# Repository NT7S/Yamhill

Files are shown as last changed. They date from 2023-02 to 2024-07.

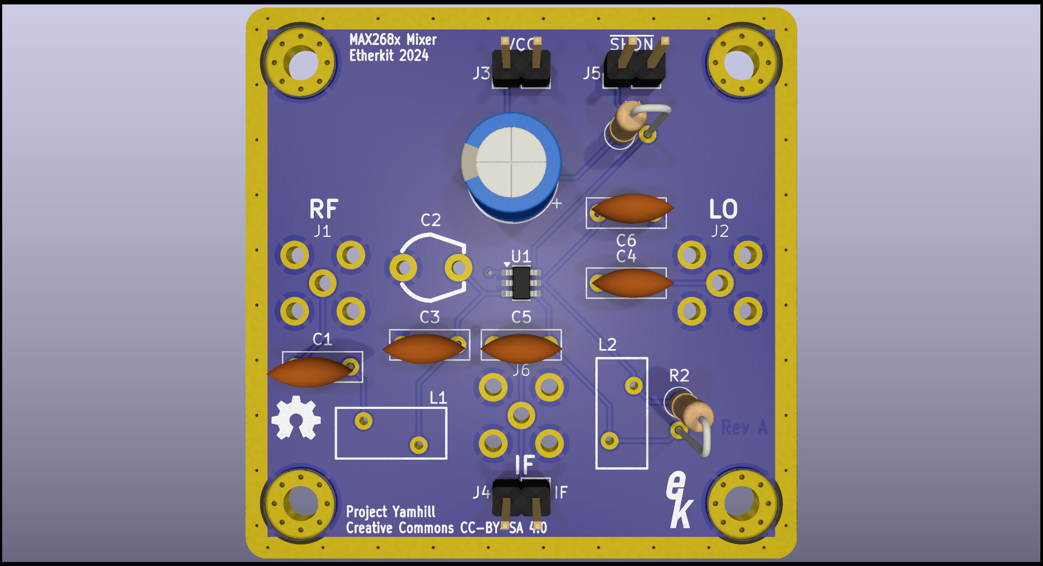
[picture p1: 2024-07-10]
PCB/YamhillMAX2680Mixer/YamhillMAX2680Mixer.png

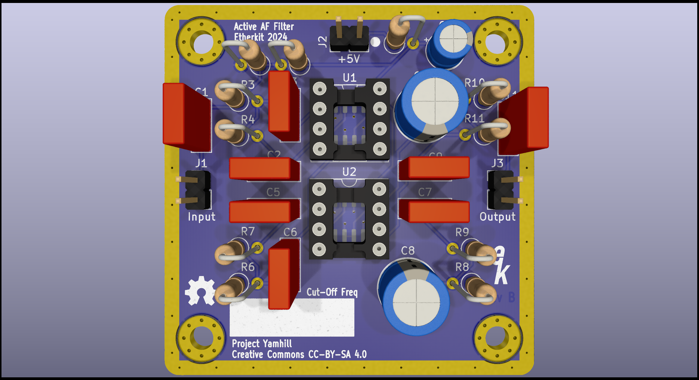
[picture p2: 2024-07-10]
PCB/YamhillActiveAFFilter/YamhillActiveAFFilter.png

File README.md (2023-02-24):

# Project Yahmill
Jason Milldrum, NT7S<br/>
Etherkit LLC<br/>

Project Yamhill is the successor to the Willamette Transceiver, also known as the qrp-l Group Project. The purpose of this endeavor is to provide a platform to learn about radio electronics at a system level. Modules that correspond to the blocks of a block diagram will be the basis upon which different types of radio designs will be created. A modular 3D printed backplane will be the chassis, user interface, and power supply for the radio experiments. The desired goal is to have a high-performance CW QRP transceiver at the end of the main project run, however there would be the capacity to build many other types of radios from the blocks as desired, such as a SSB transceiver, run more transmit power with a linear amplifier that can provide 20 watts or more, data radio, simple receiver, different architectures such as a phasing receiver, etc.

All designs and code will be permissively open sourced so that an end user is able to build one by himself if desired. All radio design specifications will be published, along with detailed information about how the user can make his own measurements with affordable test equipment to ensure that his radio is performing as expected. Basic build information will be freely available, however for detailed instructions, please subscribe to my Substack, details below.

## Substack Community
Detailed build, test, and alignment instructions will be posted on my Substack, [Applied Etherics](https://nt7s.substack.com/). You'll also find support and the build community there.

## Architecture
The system architecture white paper can be found [here](YamhillArchitecture.md).

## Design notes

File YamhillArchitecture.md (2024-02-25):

# Project Yamhill Architecture

Jason Milldrum, NT7S<br/>
Etherkit LLC<br/>
Revision: 25 February 2024

## Overview

Project Yamhill is the successor to the Willamette Transceiver, also known as the qrp-l Group Project. The purpose of this endeavor is to provide a platform to learn about radio electronics at a system level. Modules that correspond to the blocks of a block diagram will be the basis upon which different types of radio designs will be created. A modular 3D printed backplane will be the chassis, user interface, and power supply for the radio experiments. The desired goal is to have a high-performance CW QRP transceiver at the end of the main project run, however there would be the capacity to build many other types of radios from the blocks as desired, such as a SSB transceiver, run more transmit power with a linear amplifier that can provide 20 watts or more, data radio, simple receiver, different architectures such as a phasing receiver, etc.

All designs and code will be permissively open sourced so that an end user is able to build one by himself if desired. All radio design specifications will be published, along with detailed information about how the user can make his own measurements with affordable test equipment to ensure that his radio is performing as expected.

## Backplane

The Yamhill backplane will be the foundation of every radio experiment in this project. Designed to be printed on a consumer-grade FDM 3D printer, it will hold all of the necessary block modules open-air in a reconfigurable grid, have an integrated power supply and power distribution system, have rear connectors needed for a complete transceiver, and house the front panel with the user interface, including microcontroller, LCD display, buttons, encoder tuning knob, etc.

Possibly two sizes, but we're going to start with the largest and see if there is demand for a more compact version.

### Block Module Grid

A grid of mounting holes for M3(?) screws to secure block module PCBs to the backplane will be spaced at 4 cm in each axis, with allowance for 5 mm of margin from the outside board edge at each mounting hole, with a 1 cm x 1 cm x 1 cm cable management channel being provided between each row and column of mounting holes.

Therefore, allowable PCB sizes will be 5 cm x 5 cm, 5 cm x 11 cm, 11 cm x 11 cm, 11 cm x 17 cm, etc.

### Signal Routing

DC power is to be provided by and distributed through a PCB that integrates with the backplane. Channels to be provided in the backplane (1 cm width?) for easy and neat distribution of other signals.

### On-board Rear Panel Connectors

- BNC (x2)
- SMA (x2)
- DC barrel (5.5 x 2.1 mm)
- 3.5 mm TRS (x2)
- USB-C (for UART)

### Front Panel

A front panel PCB will hold most of the user interface and brains of Project Yamhill. This PCB will be populated with:
- Raspberry Pi Pico microcontroller
- Color LCD display module with touchscreen
- Large tuning encoder
- Smaller encoders (for multifunction usage)
- AF gain pot if not encoder controlled
- A plethora of microswitch pushbuttons
- A handful of status LEDs
- ADC channels for measuring things like PSU voltage, SWR, etc.
- Two 3.5 mm TRS jacks (Morse paddle and headphones)
- Microphone jack (RJ-45?)
- AF Power Amplifier
- Microphone Amplifier
- Speaker (not sure if front-firing or chassis-mounted)
- Transmit, mute, and extra GPIO pins available on pin headers for project use
- Audio and microphone signals routed to Pico ADC pins for future DSP usage
- Pico DAC pin routed to AF power amp for sidetone use and future DSP usage

The front panel PCB will have a USB connection for programming the microcontroller, as well as at least one UART available for rig control, debugging purposes, etc.

## Block Modules

Block modules are self-contained PCBs that will perform the functions of a block on the block diagram of a radio. Most components on front panel PCB will be SMT, and those boards sold by Etherkit will have the SMT components installed by the manufacturer. Most individual modules will be through-hole, unless there are no non-SMT options for a component.

### List

- PSU/Power Distribution (special case, backplane integration)
    - 12 V rail, derived from exterior PSU, minimum 1 A
    - 5 V rail, minimum 500 mA(?)
    - 3.3 V rail, minimum 100 mA
    - LED indicators
    - Reverse polarity and overcurrent protection
    - Inputs: 12 VDC, 2 A
    - Outputs: 12 VDC, 5 VDC regulated, 3.3 VDC regulated
- AF Power Amplifier (included in front panel PCB)
    - 60 dB AF gain
    - Able to drive a 1 W speaker or phones
    - AF gain control
    - Sidetone injection
    - Transceive muting
- AF Preamplifier For DC receiver
    - Based on W7ZOI AF Feedback Amplifier
    - ~40 dB AF gain for use in a DC receiver
    - Diplexer on input for good termination of mixer
- Grounded Gate JFET RF Preamp
    - Mainly for direct conversion receiver front end
- Microphone Amplifier (include in front panel PCB)
- Audio Filter
    - DSP CODEC?
- Double-balanced Diode Ring Mixer/Modulator
    - Option for higher than level 7?
- KISS Mixer
- Tayloe Detector
- Crystal Ladder IF Filter
    - Various bandwidths available for SSB, CW, roofing
- IF Amplifier with AGC
- Receive Bandpass Filter
- Receive Bandpass Filter MUX
- Transmit Low-pass Filter
- Transmit Low-pass Filter MUX
- Transmit/Receive Switch
- Wideband Oscillator
    - Most likely Si5351C, but open to options
- Transmit Preamplifier
- QRP Transmit Linear Amplifier
    - Maximum power output 5 W
- Higher Power Transmit Linear Amplifier
    - Maximum power output 20 W
- GPS Receiver
    - 10 MHz ref out
    - 1 PPS out
- SWR Bridge
- S-meter Detector
- Signal Distribution(?)
- Experimenter Board (grid of Manhattan pads, connectors pads available on edge, few different sizes)

### Inter-module RF Signal Interconnects

SMA PCB mount jacks and RG-316 coax with SMA connectors

### Inter-module DC/AF Signal Interconnects

0.1 inch pin headers and Dupont wiring harnesses

## Proposed Learning Units

- Direct Conversion Receiver
- QRP CW Transmitter
- DSB Transmitter/Transceiver
- Superheterodyne CW QRP Transceiver
- WSPR Transmitter
- Superheterodyne SSB/CW QRP Transceiver

## QRP CW Transceiver Target Specifications

TBD

## Expected Required Test Equipment

- DVM
- Oscilloscope
- Spectrum analyzer such as tinySA
- VNA such as nanoVNA

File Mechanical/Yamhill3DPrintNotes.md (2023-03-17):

# Project Yamhill 3D Print Notes

The Project Yamhill backplane was designed so that it could printed on a consumer-grade FDM 3D printer. Since the total size of the backplane is 350 mm x 360 mm, the backplane is composed of four modular sections that are connected together with support brackets and M3x5 screws. Two right side and two left side modules comprise the entire base of the backplane. The front panel is secured to the front of the backplane using pairs of support brackets connected to screw holes on the vertical side of the backplane blocks.

## Material
This backplane is designed to be printed in PETG filament, although other materials such as ABS may work as well. PLA is not recommened due to its unsuitable properties for affixing screws directly to it. PLA may be usable if you modify the screw holes to accept brass heat-set inserts.

## Suggest Slicer Settings
- Infill: 20%
- Wall Line Count: 3
- Top/Bottom Layer Count: 4
- Generate Support: On (for the cable channels)

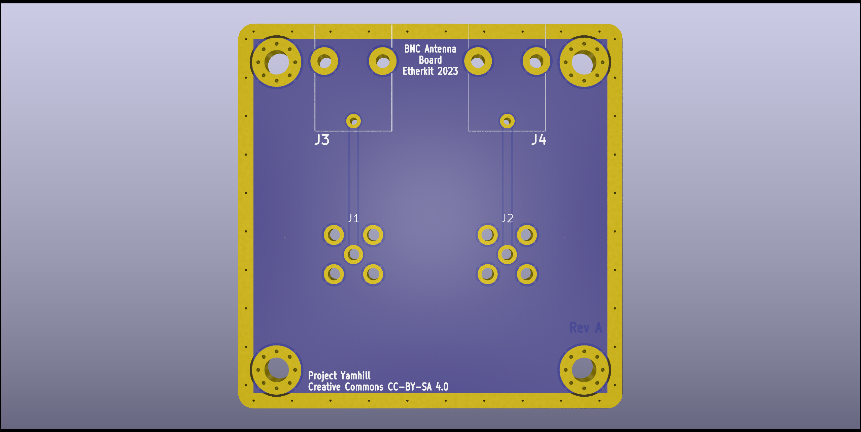
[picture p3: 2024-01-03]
PCB/YamhillBNCAntennaBoard/YamhillBNCAntennaBoard.png

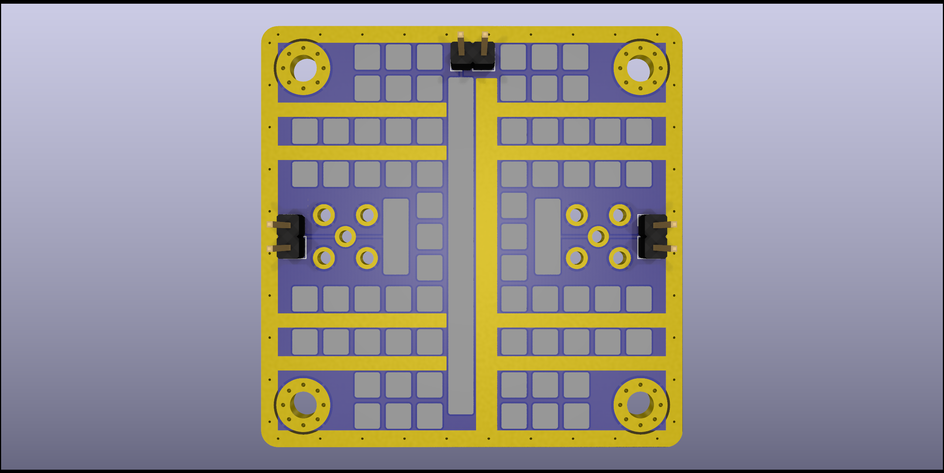
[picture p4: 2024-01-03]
PCB/YamhillProtoBoard1x1/YamhillProtoBoard1x1.png

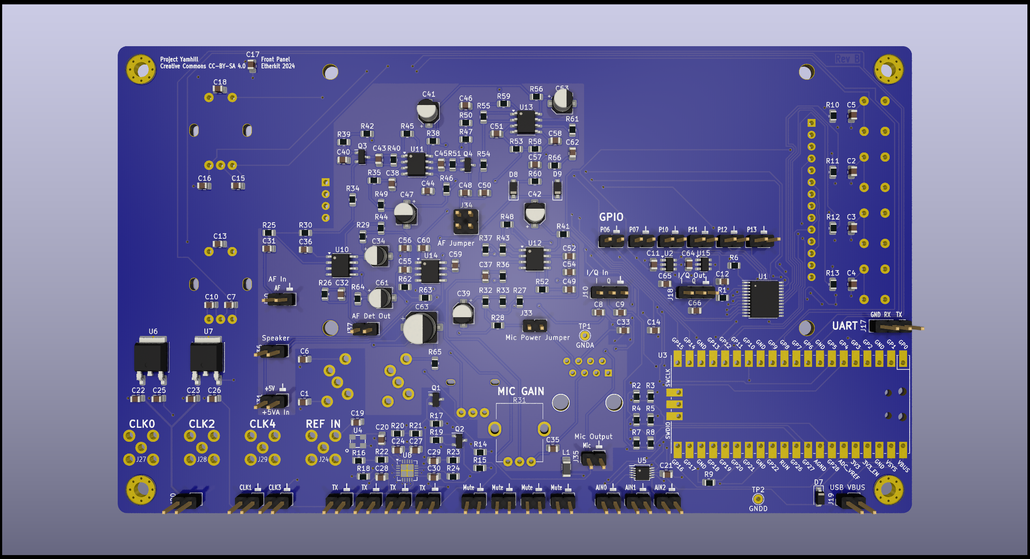
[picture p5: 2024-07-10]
PCB/YamhillFrontPanel/YamhillFrontPanelBack.png

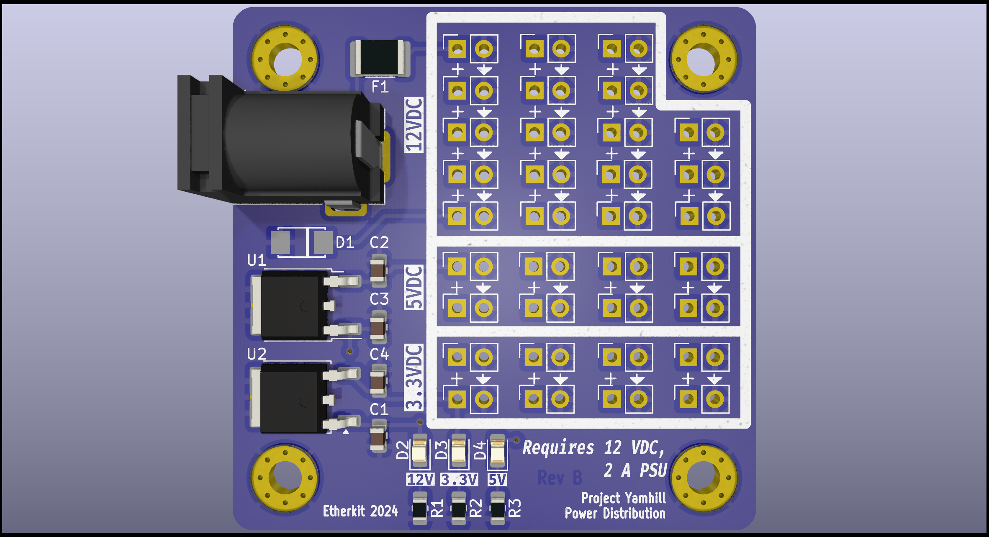
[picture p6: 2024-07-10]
PCB/YamhillPowerDistribution/YamhillPowerDistribution.png

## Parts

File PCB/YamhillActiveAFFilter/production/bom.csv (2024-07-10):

Designator | Footprint | Quantity | Value | LCSC Part #
C1, C11 | C_Rect_L7.0mm_W2.5mm_P5.00mm | 2 | 1u
C10, C8 | CP_Radial_D8.0mm_P3.50mm | 2 | C_Small
C2, C3, C5, C6, C7, C9 | C_Rect_L7.0mm_W2.5mm_P5.00mm | 6 | C_Small
C4 | CP_Radial_D5.0mm_P2.50mm | 1 | 10u
H1, H2, H3, H4 | MountingHole_3.2mm_M3_Pad_Via | 4 | MountingHole_Pad
J1 | PinHeader_1x02_P2.54mm_Vertical | 1 | Input
J2 | PinHeader_1x02_P2.54mm_Vertical | 1 | +5V
J3 | PinHeader_1x02_P2.54mm_Vertical | 1 | Output
R1, R2 | R_Axial_DIN0207_L6.3mm_D2.5mm_P2.54mm_Vertical | 2 | 10k
R10, R11, R3, R4, R6, R7, R8, R9 | R_Axial_DIN0207_L6.3mm_D2.5mm_P2.54mm_Vertical | 8 | R_US
R5 | R_Axial_DIN0207_L6.3mm_D2.5mm_P2.54mm_Vertical | 1 | 47
U1, U2 | DIP-8_SOIC-8_Combo | 2 | TLV9362

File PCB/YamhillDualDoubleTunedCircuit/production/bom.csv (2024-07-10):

Designator | Footprint | Quantity | Value | LCSC Part #
C1, C10, C12, C13, C2, C3, C5, C6, C8, C9 | C_Rect_L7.0mm_W2.5mm_P5.00mm | 10 | C
C11, C14, C4, C7 | TRIMCAP-MURATA | 4 | C_Trim
H1, H2, H3, H4 | MountingHole_3.2mm_M3_Pad_Via | 4 | MountingHole_Pad
J1, J4 | SMA_Jack_Vertical | 2 | SMA
J2, J3 | PinHeader_1x03_P2.54mm_Vertical | 2 | Filter Sel
L1, L2, L3, L4 | T37-V | 4 | L_Iron

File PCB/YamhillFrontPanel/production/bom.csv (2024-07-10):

Designator | Footprint | Quantity | Value | LCSC Part #
C1, C10, C11, C12, C13, C14, C15, C16, C17, C18, C19, C2, C21, C24, C25, C26, C27, C28, C29, C3, C30, C33, C4, C5, C55, C56, C6, C64, C65, C66, C7, C8, C9 | 0805 | 33 | 100n
C20, C52 | 0805 | 2 | 10n
C22, C23, C31, C32, C35, C37, C38, C40, C44, C46, C48, C50, C51, C54, C57, C58, C59, C60, C62 | 0805 | 19 | 1u
C34, C39, C41, C42, C47, C53, C61 | CP_Elec_4x4.5 | 7 | 10u
C36, C43, C45 | 0805 | 3 | 1n
C49 | 0805 | 1 | 2.7n
C63 | CP_Elec_6.3x5.9 | 1 | 100u
D1, D3, D4, D6 | 0805 | 4 | LED
D2, D5 | LED_WS2812B_PLCC4_5.0x5.0mm_P3.2mm | 2 | WS2812B
D7, D8, D9 | D_SOD-123 | 3 | MBRX120LF-TP
H1, H2, H3, H4 | MountingHole_3.2mm_M3_Pad_Via | 4 | MountingHole_Pad
J1, J2, J3, J4 | PinHeader_1x02_P2.54mm_Vertical | 4 | TX
J10 | PinHeader_1x03_P2.54mm_Vertical | 1 | I/Q In
J11 | PinHeader_1x02_P2.54mm_Vertical | 1 | P06
J12 | PinHeader_1x02_P2.54mm_Vertical | 1 | P07
J13 | PinHeader_1x02_P2.54mm_Vertical | 1 | P10
J14 | PinHeader_1x02_P2.54mm_Vertical | 1 | P11
J15 | PinHeader_1x02_P2.54mm_Vertical | 1 | P12
J16 | PinHeader_1x02_P2.54mm_Vertical | 1 | P13
J17 | PinHeader_1x03_P2.54mm_Vertical | 1 | UART
J18 | PinHeader_1x03_P2.54mm_Vertical | 1 | I/Q Out
J19 | PinHeader_1x02_P2.54mm_Vertical | 1 | USB VBUS
J20 | PinHeader_1x02_P2.54mm_Vertical | 1 | +12V IN
J21 | PinHeader_1x02_P2.54mm_Vertical | 1 | AIN0
J22 | PinHeader_1x02_P2.54mm_Vertical | 1 | AIN1
J23 | PinHeader_1x02_P2.54mm_Vertical | 1 | AIN2
J24 | SMA_Jack_Vertical | 1 | REF_IN
J25 | PinHeader_1x02_P2.54mm_Vertical | 1 | CLK1
J26 | PinHeader_1x02_P2.54mm_Vertical | 1 | CLK3
J27 | SMA_Jack_Vertical | 1 | CLK0
J28 | SMA_Jack_Vertical | 1 | CLK2
J29 | SMA_Jack_Vertical | 1 | CLK4
J30 | PinHeader_1x02_P2.54mm_Vertical | 1 | AF In
J31 | PinHeader_1x02_P2.54mm_Vertical | 1 | +5VA In
J32 | RJ45_OST_PJ012-8P8CX_Vertical | 1 | Microphone
J33 | PinHeader_1x02_P2.54mm_Vertical | 1 | Mic Power Jumper
J34 | PinHeader_2x02_P2.54mm_Vertical | 1 | AF Jumper
J35 | PinHeader_1x02_P2.54mm_Vertical | 1 | Mic Output
J36 | PinHeader_1x02_P2.54mm_Vertical | 1 | Speaker
J37 | PinHeader_1x02_P2.54mm_Vertical | 1 | AF Det Out
J38 | Kycon_STX-3680-5NB | 1 | Headphones
J5, J6, J7, J8 | PinHeader_1x02_P2.54mm_Vertical | 4 | MUTE
J9 | Kycon_STX-3680-5NB | 1 | Paddles
L1 | 1206 | 1 | Fair-Rite 2512066017Y1
Q1, Q2, Q3, Q4 | SOT-23 | 4 | 2N7002
R1, R18, R32, R33, R40, R44, R48, R49, R51, R52, R59, R6, R61 | 0805 | 13 | 10k
R10, R11, R12, R13 | 0805 | 4 | 330
R14, R15, R17, R19, R54 | 0805 | 5 | 4.7k
R16, R20, R21, R22, R23, R24, R29, R38, R41, R56 | 0805 | 10 | 47
R2, R3, R4, R5, R7, R8 | 0805 | 6 | 47k
R25 | 0805 | 1 | 100
R26, R35, R36, R39, R46, R50, R53, R55, R58, R62, R63, R64 | 0805 | 12 | 100k
R27, R37, R42, R9 | 0805 | 4 | 470
R28 | 0805 | 1 | 7.5k
R30, R34, R45, R47, R60, R66 | 0805 | 6 | 1k
R31 | Bournes_PTV09A-4 | 1 | 5k trim
R43 | 0805 | 1 | 270k
R57 | Alps_RK09L1140 | 1 | 10k
R65 | 0805 | 1 | 150
S1, S2, S3, S4 | E-Switch_TL1105 | 4 | PUSHBUTTON_TACTILE
SW1 | Bournes_PEC11R-4xxxF-Sxxxx | 1 | Tune
SW2 | Bournes_PEC11R-4xxxF-Sxxxx | 1 | Multifunction
TP1 | TestPoint_THTPad_D2.0mm_Drill1.0mm | 1 | GNDA
TP2 | TestPoint_THTPad_D2.0mm_Drill1.0mm | 1 | GNDD
U1 | TSSOP-24_6.1x7.8mm_P0.65mm | 1 | TCAL6416PWR
U10, U11, U12, U13 | SOIC-8_3.9x4.9mm_P1.27mm | 4 | TLV9362
U14 | SOIC-8_3.9x4.9mm_P1.27mm | 1 | LM4875
U15, U2 | SOT-23-6 | 2 | MCP4725A1T-E/CH
U3 | RPi_Pico_SMD_TH | 1 | Pico
U4 | ASTX-H11-25.000MHZ-T | 1 | ATX-H11-F-25.000MHZ-F25-T
U5 | TSSOP-10_3x3mm_P0.5mm | 1 | ADS1115IDGS
U6 | TO-252-2 | 1 | UA78M33CKVURG3
U7 | TO-252-2 | 1 | UA78M05IKVURG3
U8 | QFN-20-1EP_4x4mm_P0.5mm_EP2.7x2.7mm_ThermalVias | 1 | Si5351C
U9 | ST7796_4.0in | 1 | 4" TFT LCD ST7796S

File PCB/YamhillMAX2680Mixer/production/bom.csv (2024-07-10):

Designator | Footprint | Quantity | Value | LCSC Part #
C1, C4, C6 | C_Disc_D7.0mm_W2.5mm_P5.00mm | 3 | 100n
C2 | TRIMCAP-MURATA | 1 | ~
C3 | C_Disc_D7.0mm_W2.5mm_P5.00mm | 1 | ~
C5 | C_Disc_D7.0mm_W2.5mm_P5.00mm | 1 | 1u
C7 | CP_Radial_D8.0mm_P5.00mm | 1 | 100u
H1, H2, H3, H4 | MountingHole_3.2mm_M3_Pad_Via | 4 | MountingHole_Pad
J1 | SMA_Jack_Vertical | 1 | RF
J2 | SMA_Jack_Vertical | 1 | LO
J3 | PinHeader_1x02_P2.54mm_Vertical | 1 | VCC
J4 | PinHeader_1x02_P2.54mm_Vertical | 1 | IF
J5 | PinHeader_1x02_P2.54mm_Vertical | 1 | ~{SHDN}
J6 | SMA_Jack_Vertical | 1 | IF
L1, L2 | T37-V | 2 | T37-x
R1 | R_Axial_DIN0207_L6.3mm_D2.5mm_P2.54mm_Vertical | 1 | 10k
R2 | R_Axial_DIN0207_L6.3mm_D2.5mm_P2.54mm_Vertical | 1 | ~
U1 | SOT-23-6 | 1 | ~

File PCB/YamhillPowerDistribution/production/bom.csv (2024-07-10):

Designator | Footprint | Quantity | Value | LCSC Part #
C1, C3 | 0805 | 2 | 330n
C2, C4 | 0805 | 2 | 100n
D1 | DO-214AC | 1 | SK56A-LTP
D2, D3, D4 | 0805 | 3 | LED
F1 | 1812 | 1 | SMD1812B260TF/16
H1, H2, H3, H4 | MountingHole_3.2mm_M3_Pad_Via | 4 | MountingHole_Pad
J1 | CUI_PJ-202AH | 1 | CUI PJ-202AH
J10, J11, J12, J13, J14, J15, J16, J17, J26, J27, J28, J29, J30, J31, J32, J33, J34, J35 | PinSocket_1x02_P2.54mm_Vertical | 18 | 12VDC
J18, J19, J20, J21, J22, J23, J24, J25 | PinSocket_1x02_P2.54mm_Vertical | 8 | 3.3VDC
J2, J3, J4, J5, J6, J7, J8, J9 | PinSocket_1x02_P2.54mm_Vertical | 8 | 5VDC
R1 | 0805 | 1 | 2.7k
R2 | 0805 | 1 | 660
R3 | 0805 | 1 | 1k
U1 | TO-252-2 | 1 | UA78M05IKVURG3
U2 | TO-252-2 | 1 | UA78M33CKVURG3

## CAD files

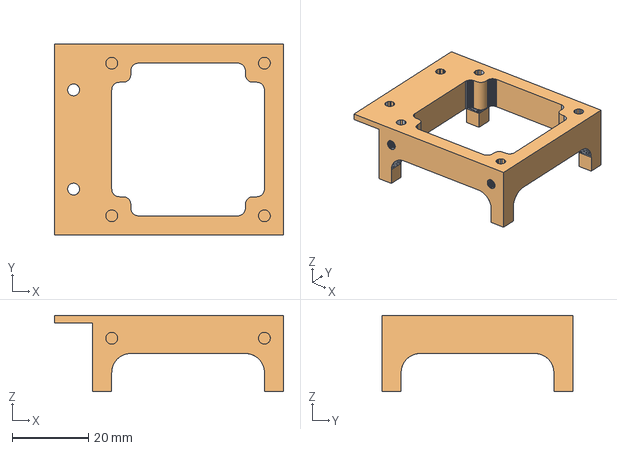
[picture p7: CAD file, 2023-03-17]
Mechanical/BackplaneBlockTest.FCStd
60.0 x 50.0 x 20.0 mm
Fusion (Meshed)

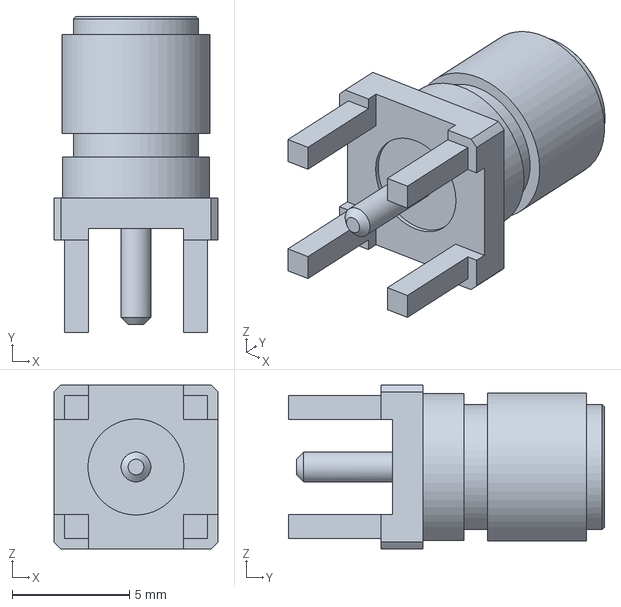
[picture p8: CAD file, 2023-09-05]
PCB/3DModels/SMA-J-P-H-ST-TH1.igs
7.00 x 13.5 x 7.00 mm

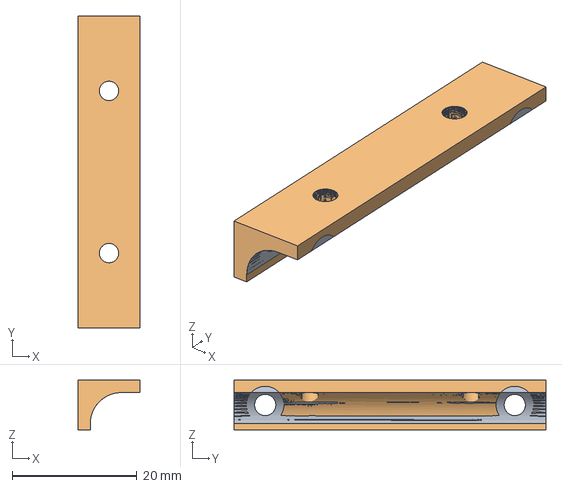
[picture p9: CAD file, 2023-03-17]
Mechanical/BackplaneSupport.FCStd
10.0 x 50.0 x 8.00 mm
Cut001 (Solid) (Meshed)

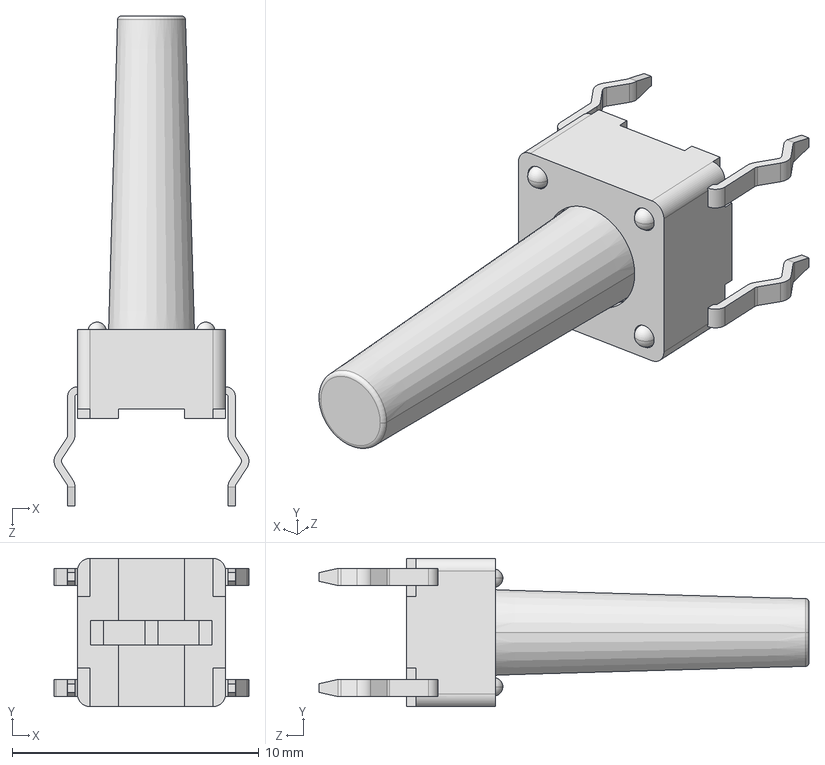
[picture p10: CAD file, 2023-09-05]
PCB/3DModels/TL1105YF160Q.step
7.89 x 6.00 x 19.8 mm

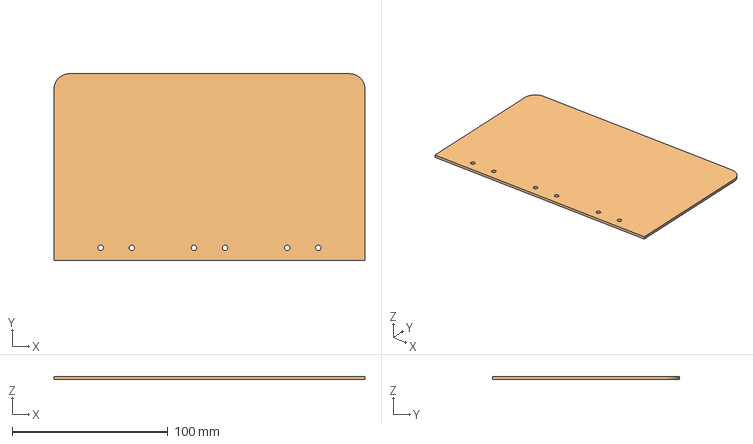
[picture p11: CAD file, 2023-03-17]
Mechanical/BackplaneFrontPanel.FCStd
200.0 x 120.0 x 2.00 mm
Pocket (Meshed)

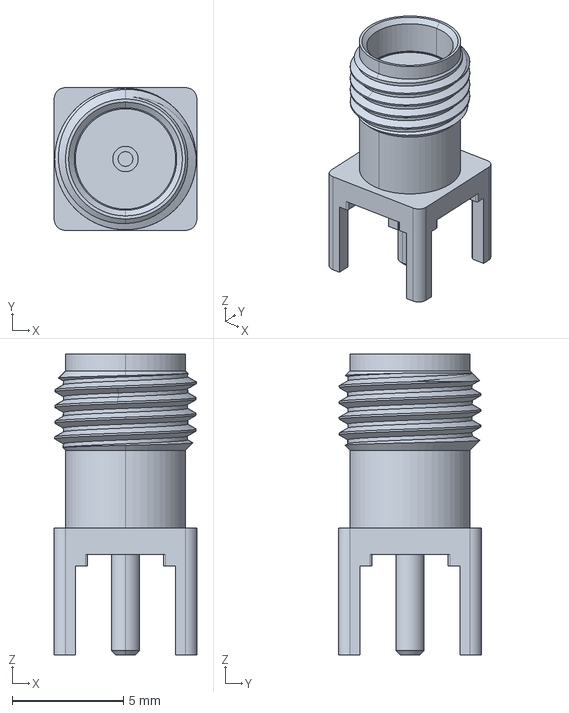
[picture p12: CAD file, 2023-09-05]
PCB/3DModels/c-5-1814832-2-c-3d.igs
6.40 x 6.40 x 13.5 mm

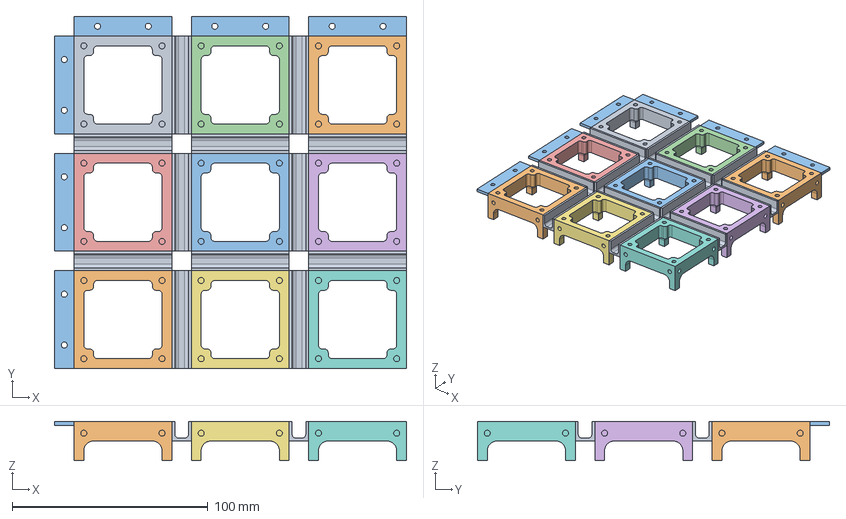
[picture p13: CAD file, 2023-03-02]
Mechanical/Backplane.FCStd
180.0 x 180.0 x 20.0 mm
BackplaneChannel x 12
BackplaneBlock
BackplaneBlock001
BackplaneBlock002
BackplaneBlock003
BackplaneBlock004
BackplaneBlock005
BackplaneBlock006
BackplaneBlock007
BackplaneBlock008
Lip x 6

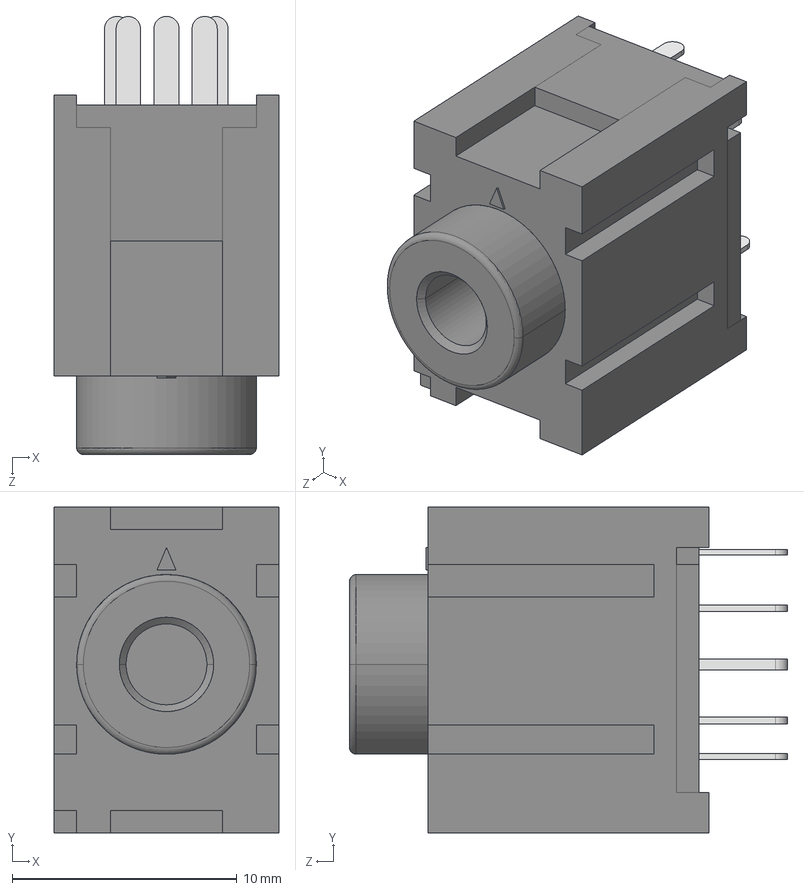
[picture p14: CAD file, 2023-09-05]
PCB/3DModels/STX-3680-5NB_rA3.IGS
10.0 x 14.5 x 19.5 mm

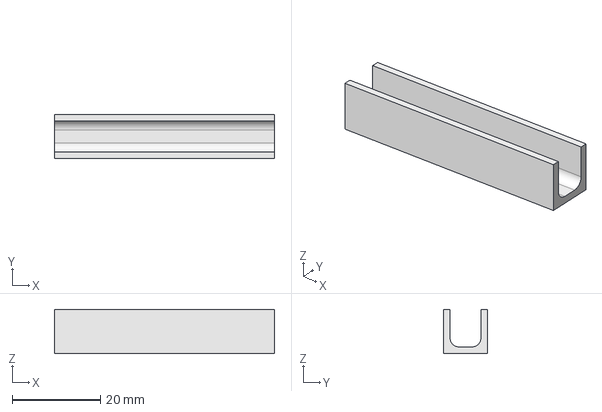
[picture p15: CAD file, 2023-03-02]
Mechanical/BackplaneChannel.FCStd
50.0 x 10.0 x 10.0 mm

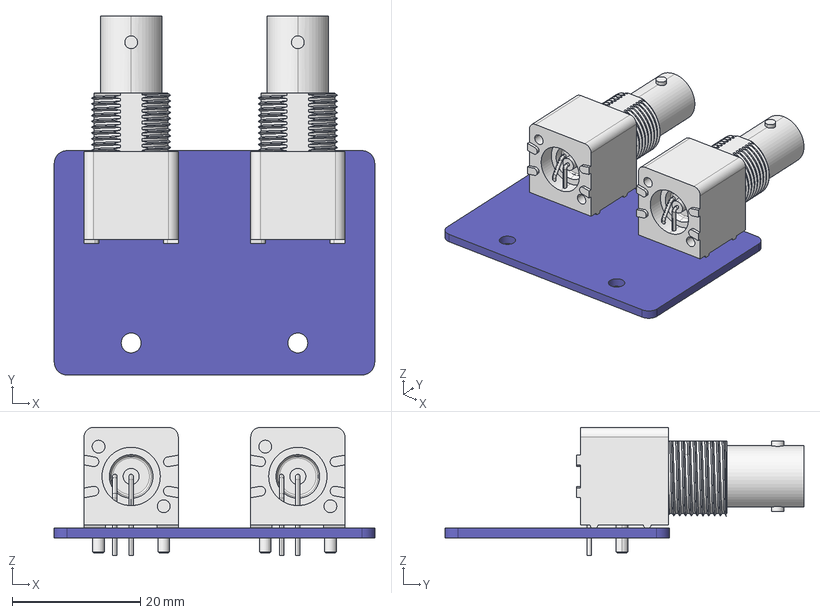
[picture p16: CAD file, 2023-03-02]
Mechanical/BNCBoard.FCStd
50.0 x 56.0 x 20.0 mm
BNC1
BNC002

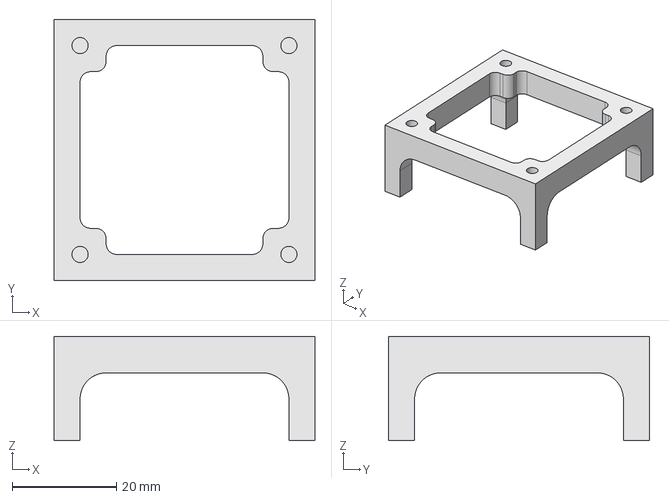
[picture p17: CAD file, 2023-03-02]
Mechanical/BackplaneBlock.FCStd
50.0 x 50.0 x 20.0 mm

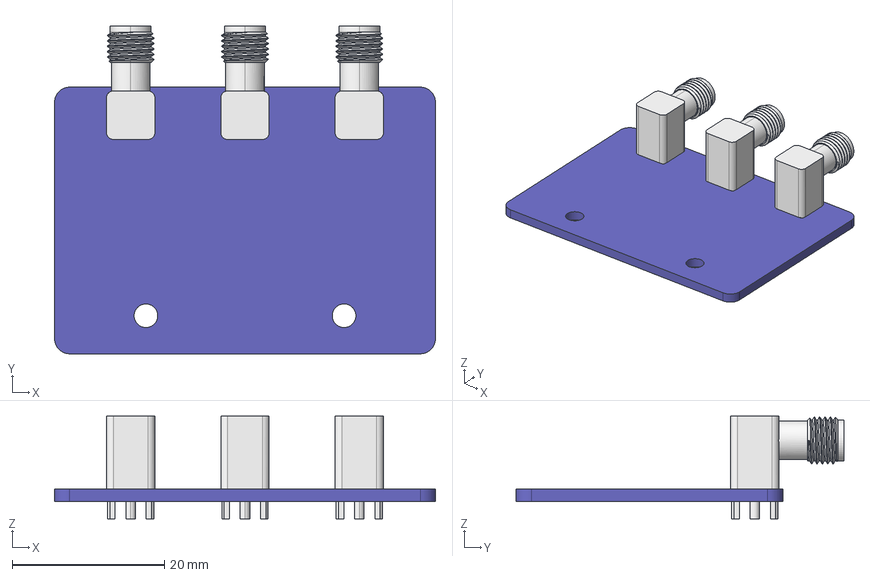
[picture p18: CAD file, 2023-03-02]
Mechanical/SMABoard.FCStd
50.0 x 43.0 x 13.5 mm
SMA1
SMA002
SMA003

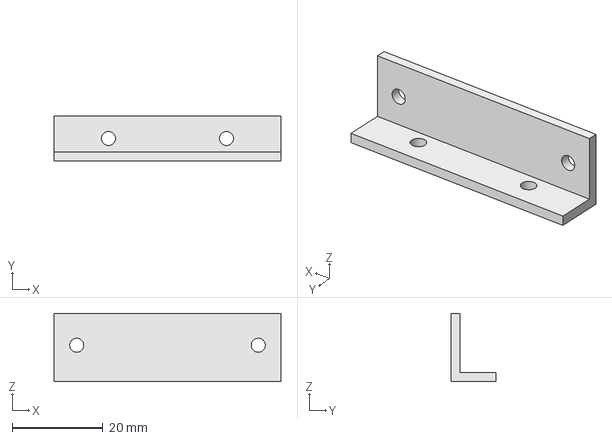
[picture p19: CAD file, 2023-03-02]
Mechanical/BackplaneLBracket.FCStd
50.0 x 10.0 x 15.0 mm

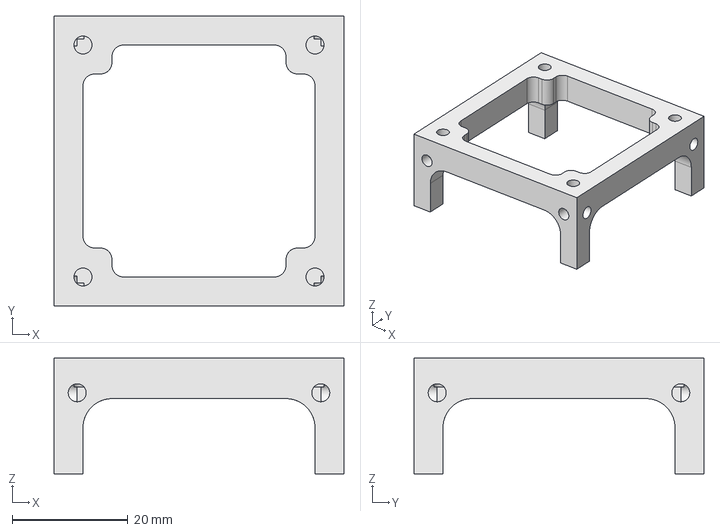
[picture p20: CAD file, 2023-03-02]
Mechanical/BackplaneBlockMountingHoles.FCStd
50.0 x 50.0 x 20.0 mm

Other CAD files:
Mechanical/BackplaneBlockTest.stl
Mechanical/BackplaneFrontPanel.stl
Mechanical/BackplaneSupport.stl

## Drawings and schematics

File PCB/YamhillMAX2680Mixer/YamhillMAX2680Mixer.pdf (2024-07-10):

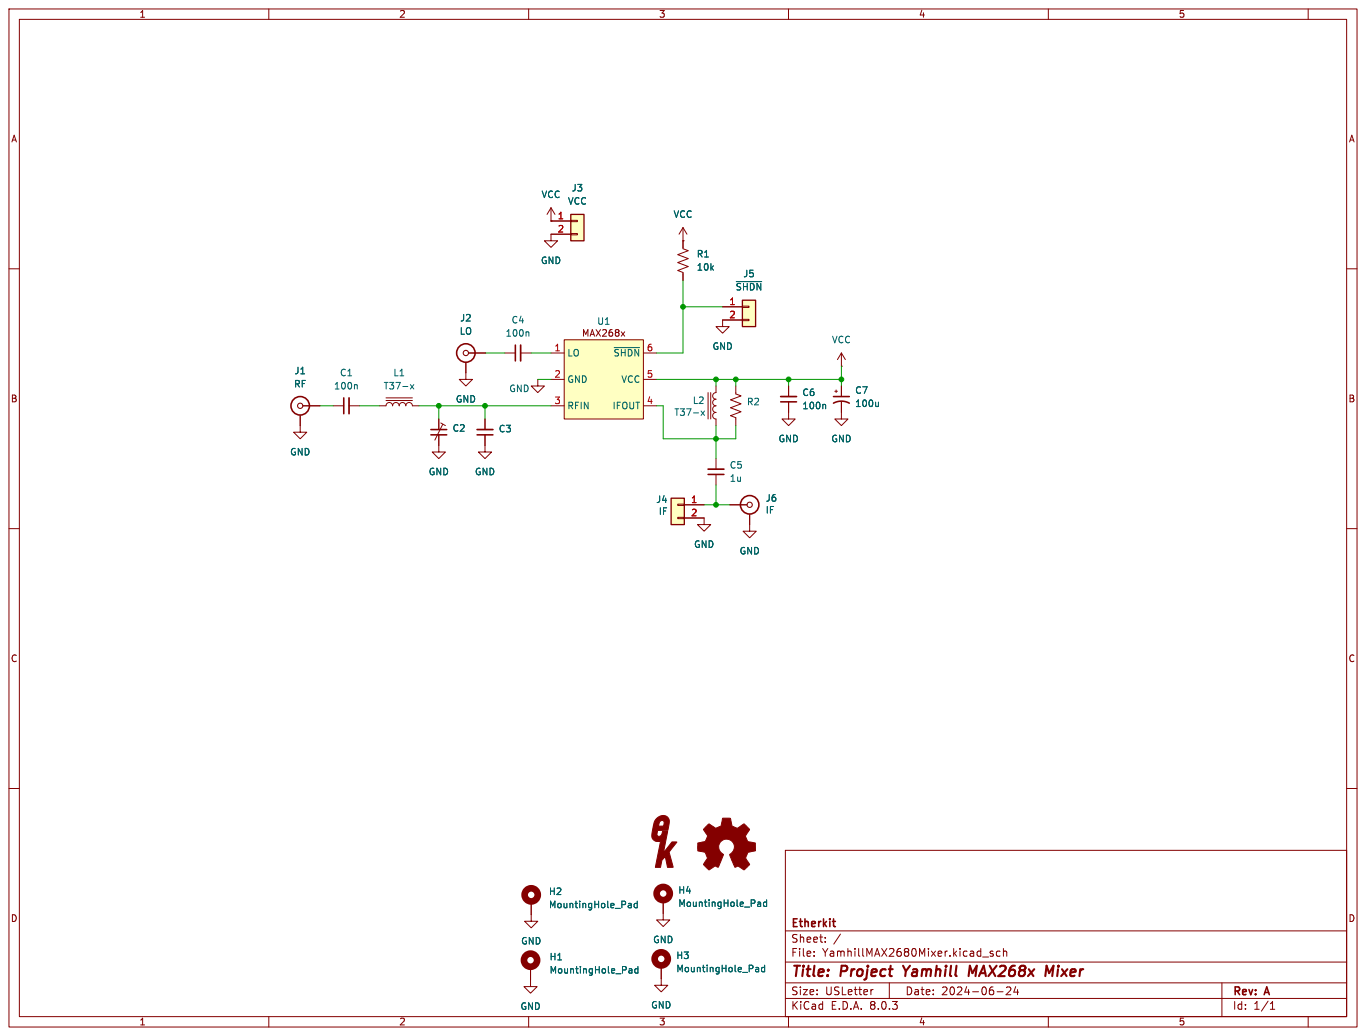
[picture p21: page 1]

Id: 1/1 Title: Project Yamhill MAX268x Mixer File: YamhillMAX2680Mixer.kicad_sch Sheet: / Etherkit

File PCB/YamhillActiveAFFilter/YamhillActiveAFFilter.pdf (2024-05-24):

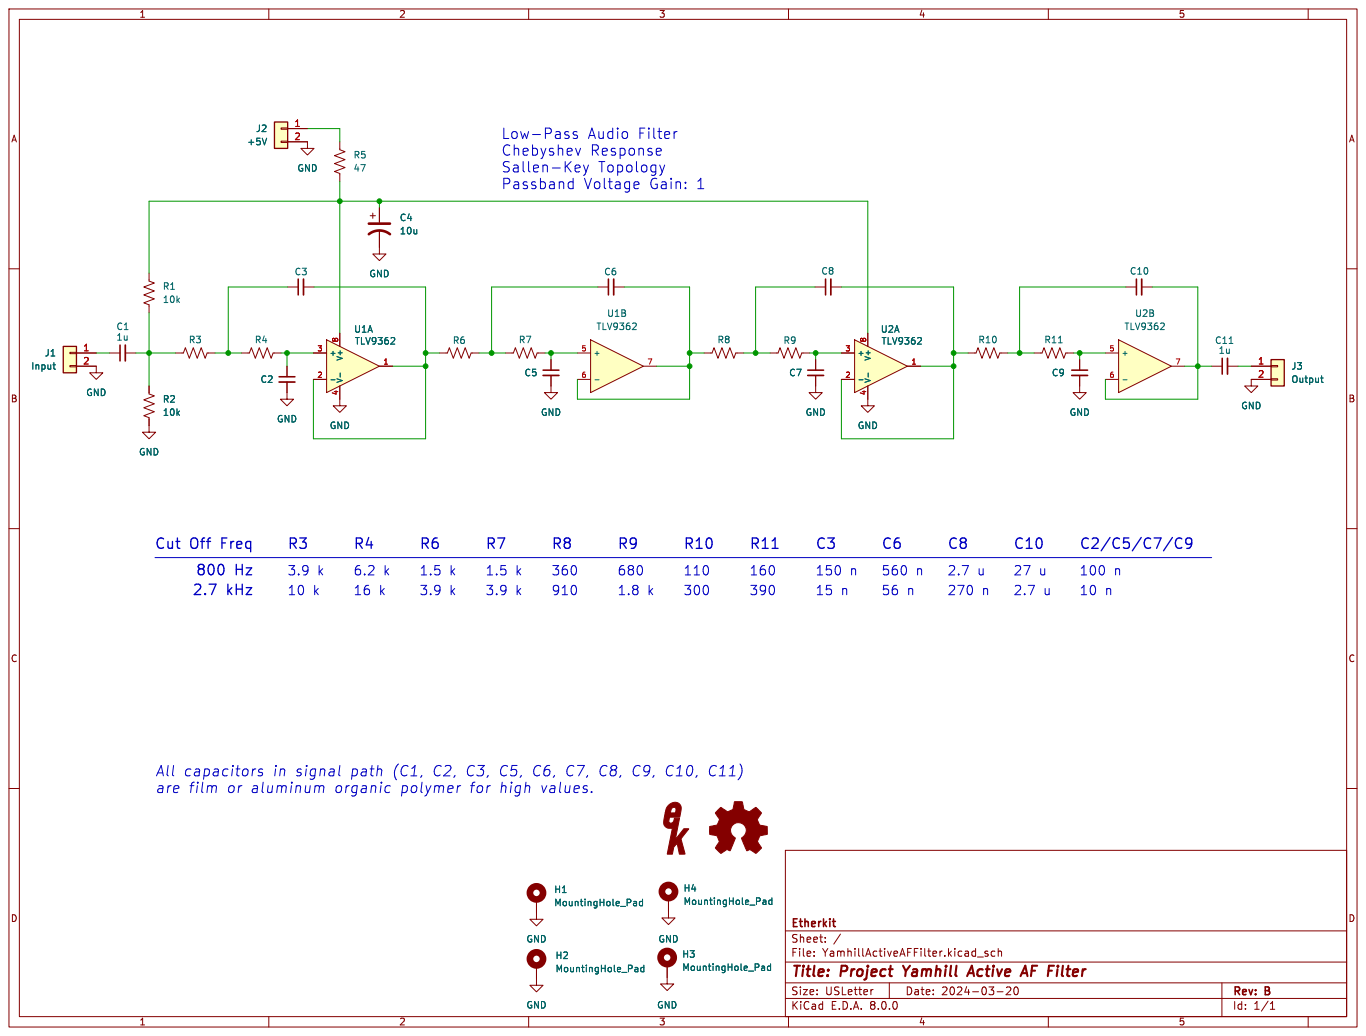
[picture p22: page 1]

Id: 1/1 Title: Project Yamhill Active AF Filter File: YamhillActiveAFFilter.kicad_sch Sheet: / Etherkit

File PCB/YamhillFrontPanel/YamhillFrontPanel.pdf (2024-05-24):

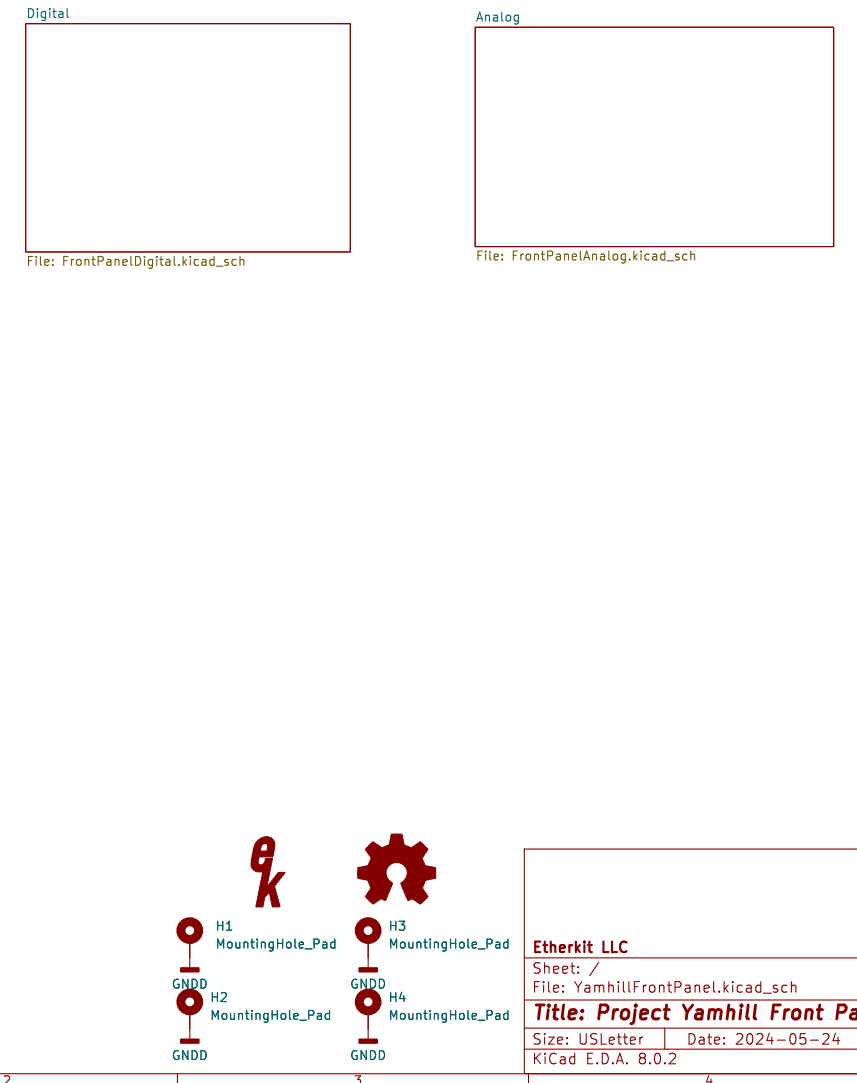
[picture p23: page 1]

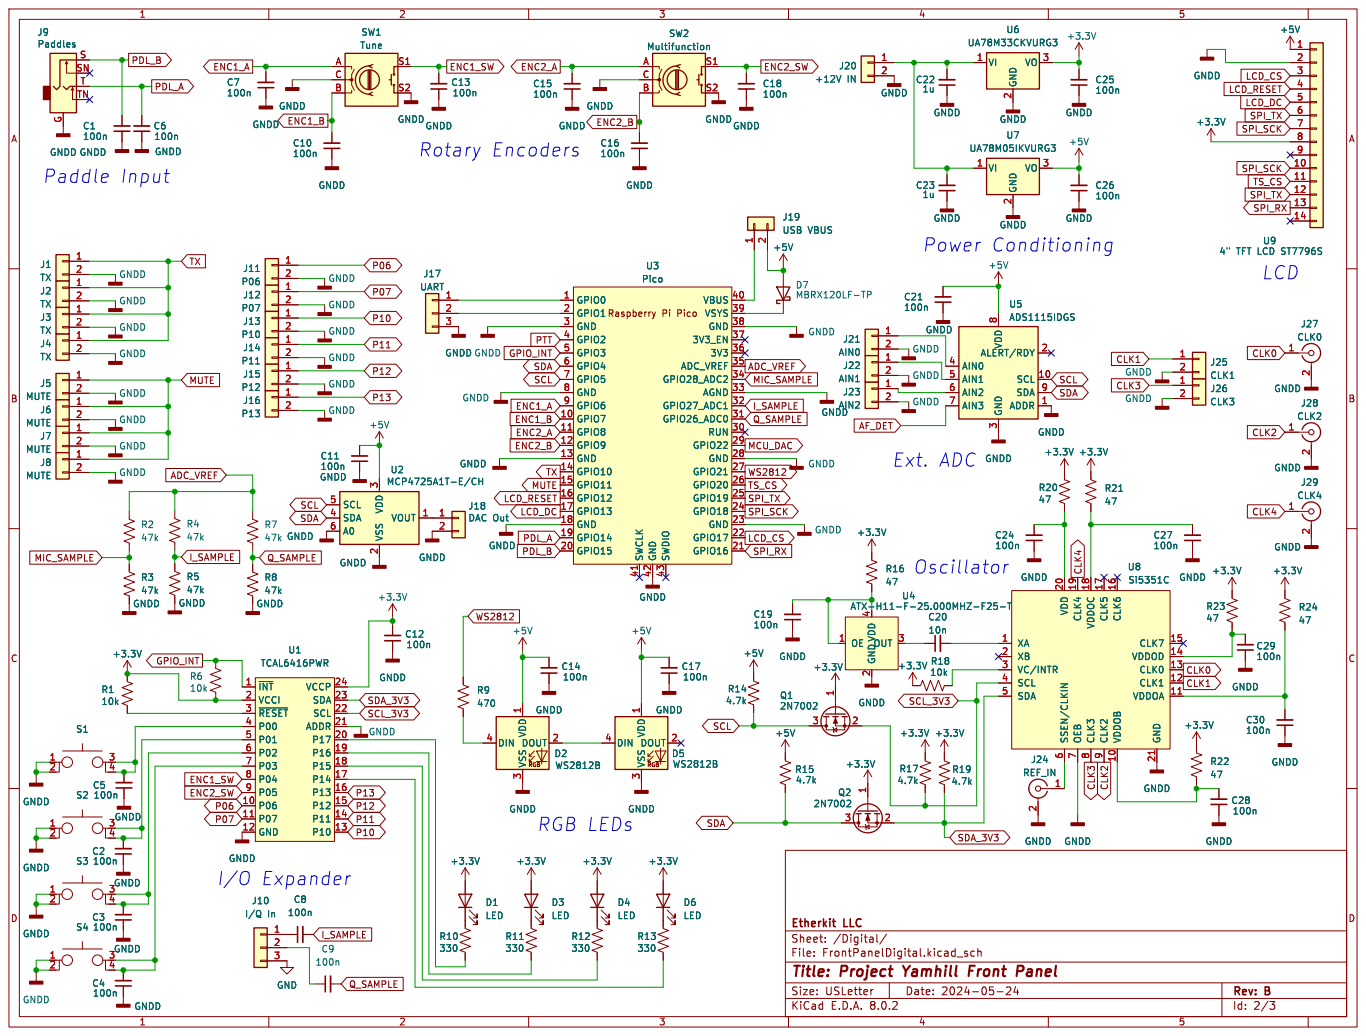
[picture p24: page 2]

2 VO 3 GNDD GNDD GNDD

3 AIN0 4 AIN1 5 AIN2 6 AIN3 7 VDD
J25 CLK1 ADDR 1 SCL 10 ALERT/RDY 2 GND

ADDR 1 SCL 10 ALERT/RDY 2 GND

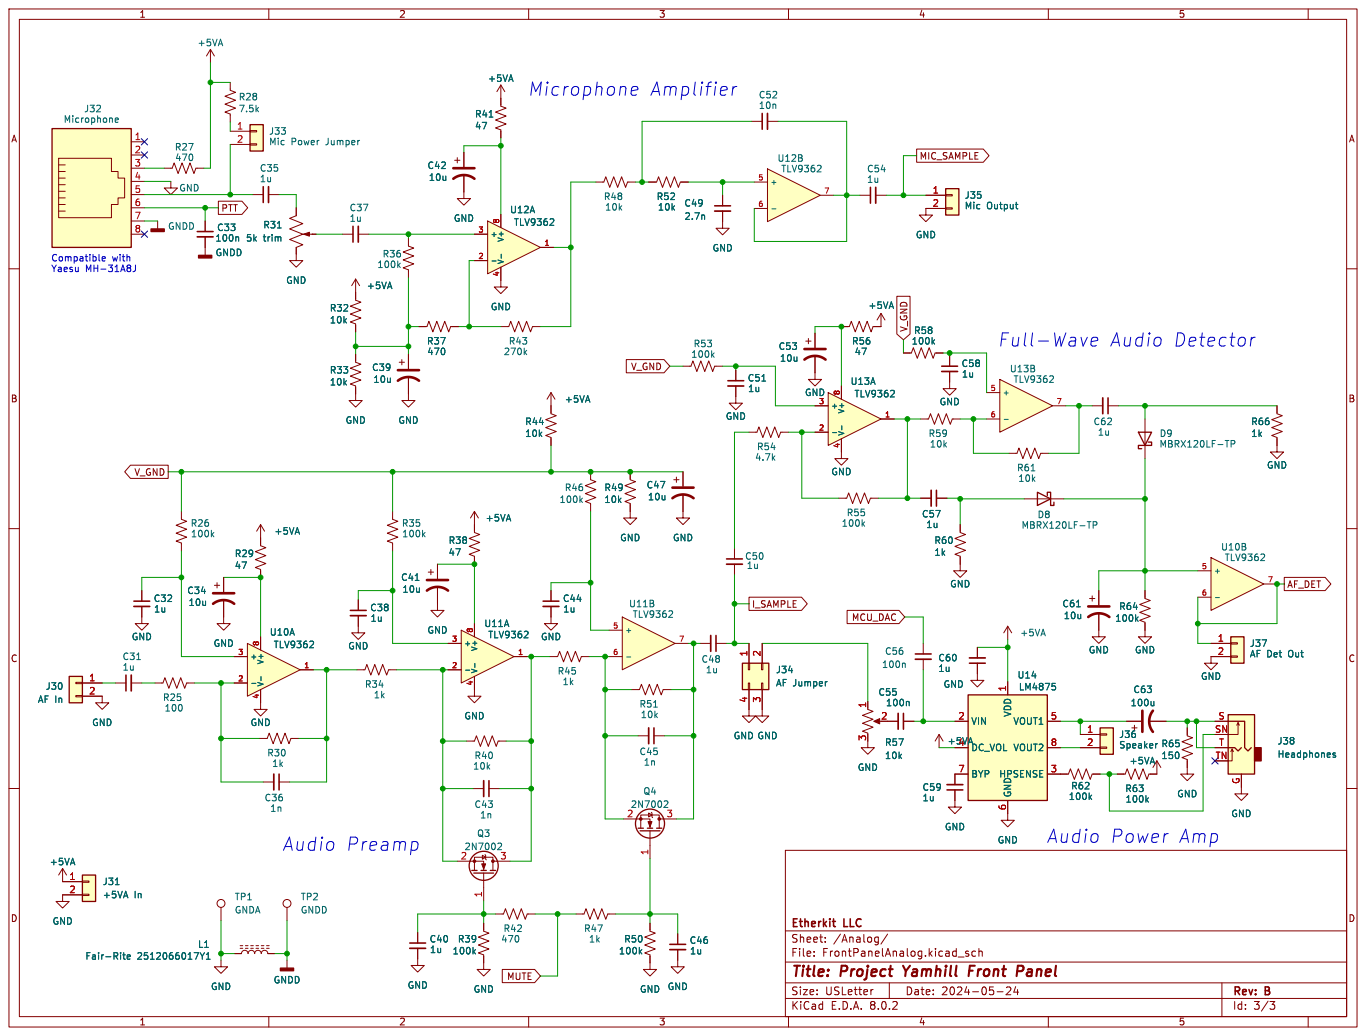
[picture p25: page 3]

J37 AF Det Out GND GND
LM4875 GND

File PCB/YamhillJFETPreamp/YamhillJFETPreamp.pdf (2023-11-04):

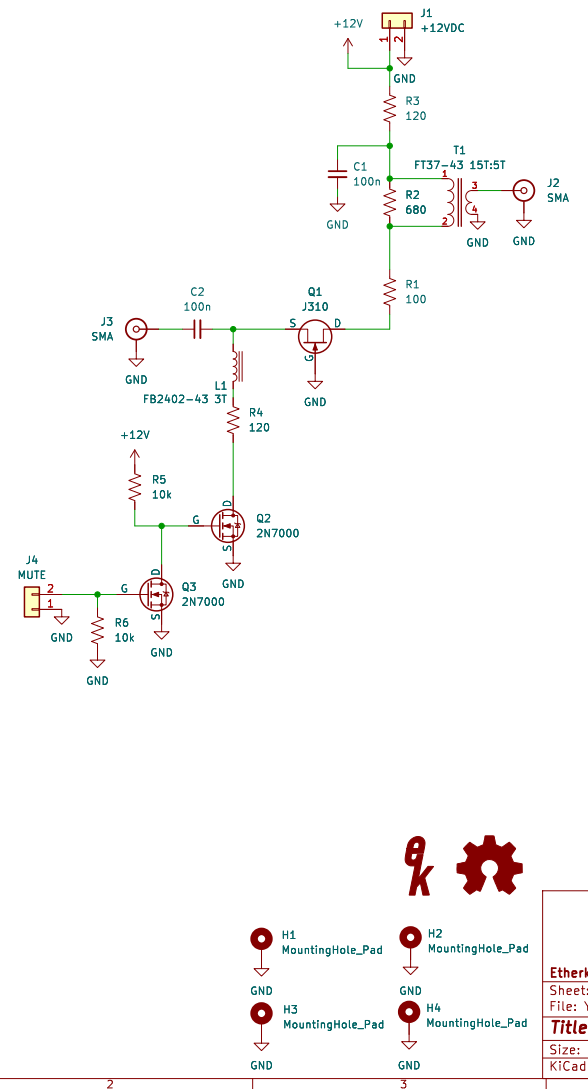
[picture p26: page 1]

Id: 1/1 Title: Project Yamhill File: YamhillJFETPreamp.kicad_sch Sheet: / Etherkit

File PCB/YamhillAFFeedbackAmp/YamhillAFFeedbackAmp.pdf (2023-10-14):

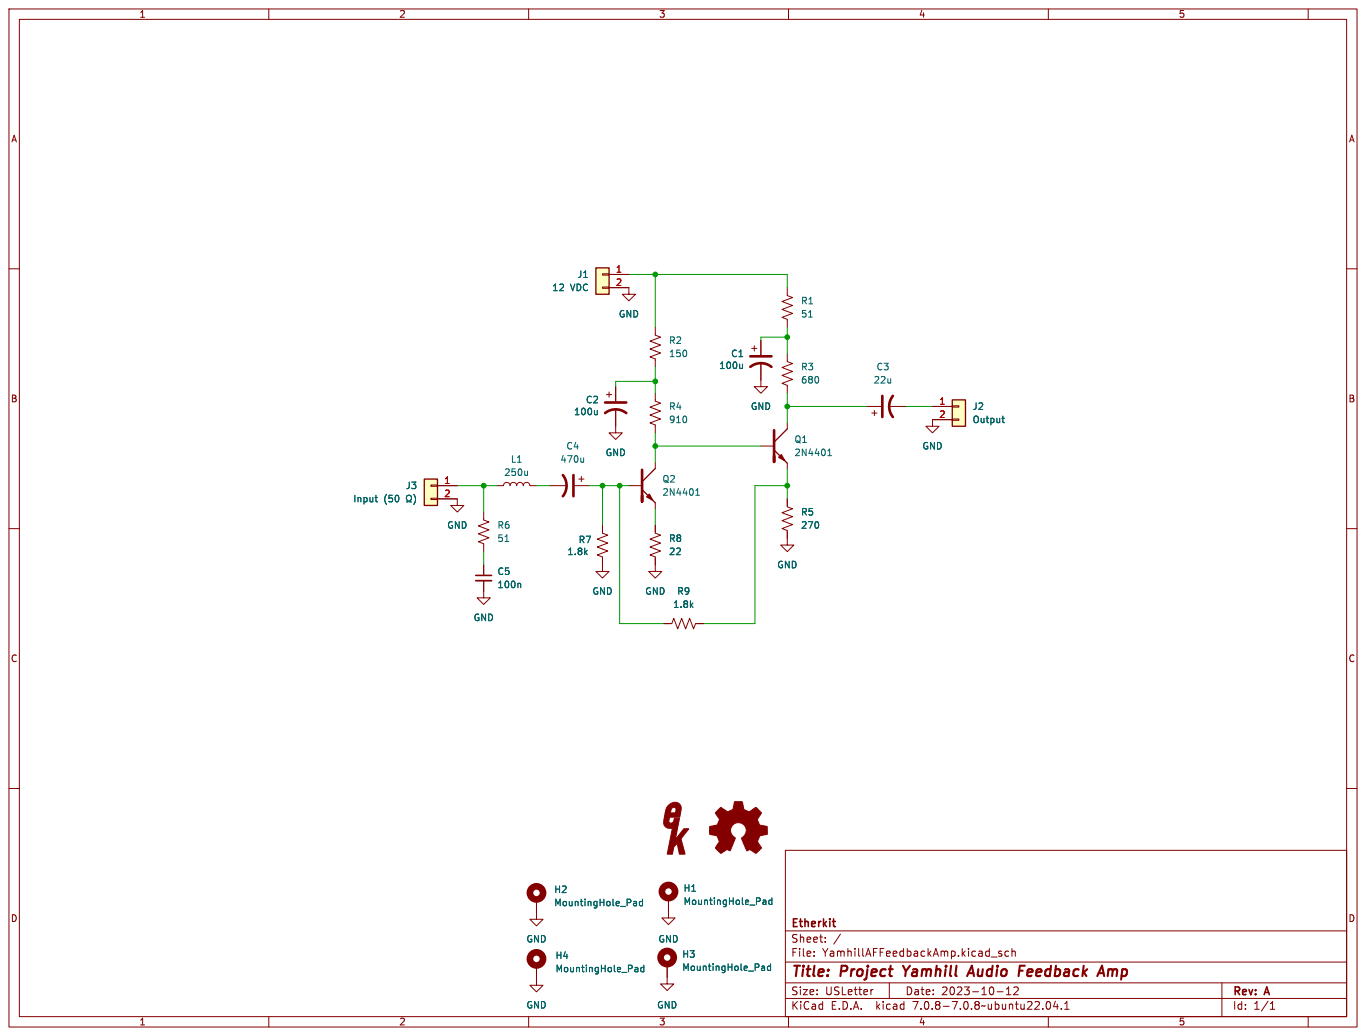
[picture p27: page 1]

File: YamhillAFFeedbackAmp.kicad_sch Sheet: / Etherkit GND

Id: 1/1 Title: Project Yamhill Audio Feedback Amp

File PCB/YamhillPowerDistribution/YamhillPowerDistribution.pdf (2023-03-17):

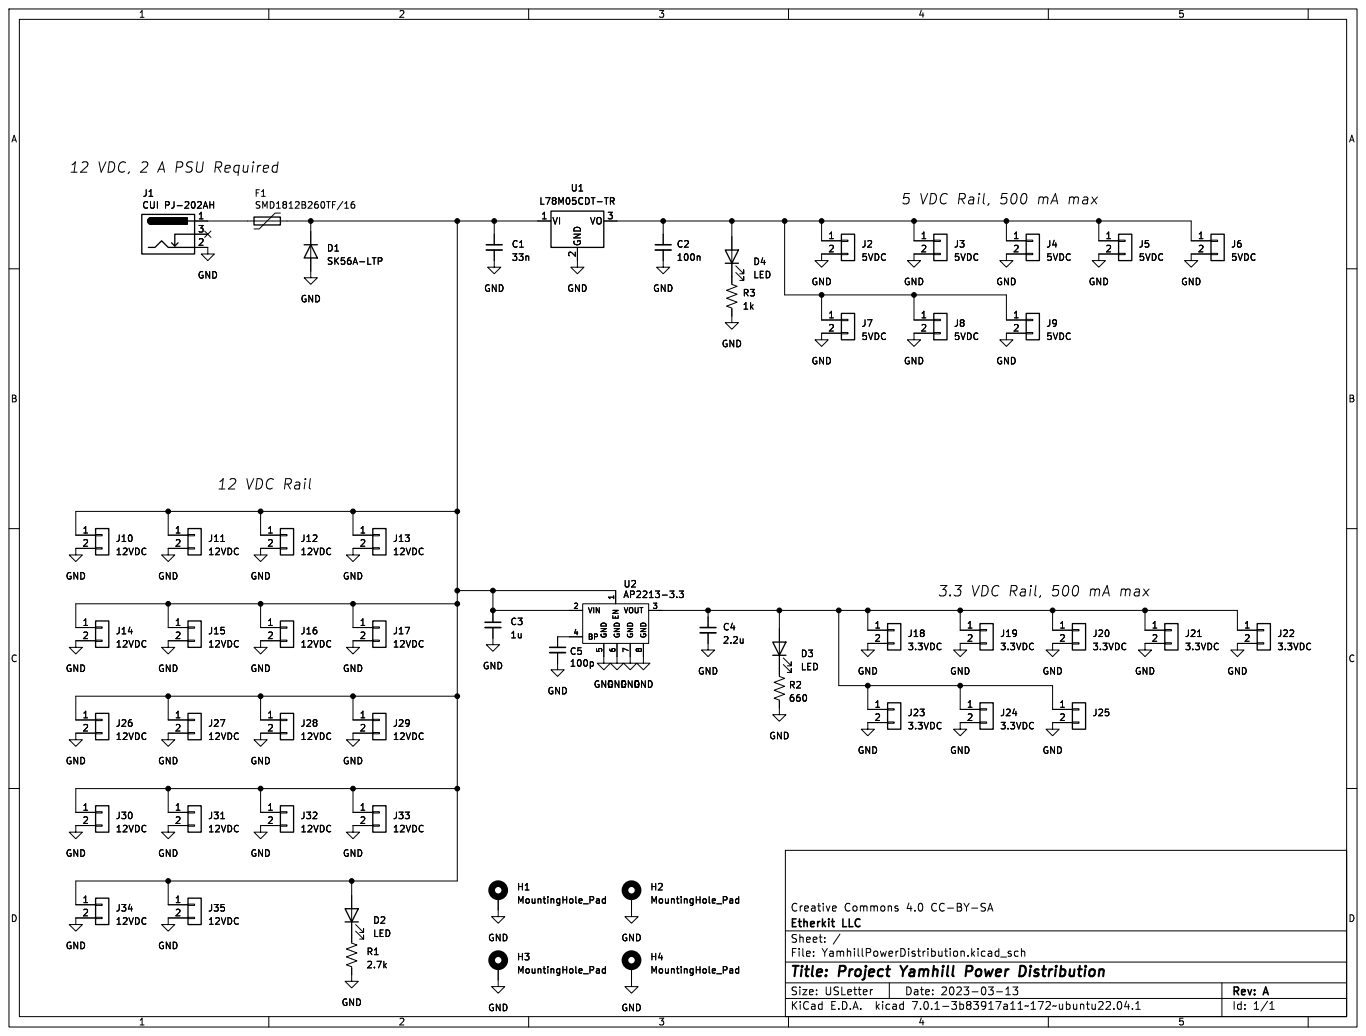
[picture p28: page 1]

D1SK56A-LTP GND 12 VDC, 2 A PSU Required

5 VDC Rail, 500 mA max

3.3 VDC Rail, 500 mA max 12 VDC Rail

1 VIN 2 VOUT 3 BP 4 GND

Creative Commons 4.0 CC-BY-SA

Id: 1/1 Title: Project Yamhill Power Distribution

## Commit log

2023-03-02 Add backplane design
    [BNCBoard.FCStd, Backplane.FCStd, BackplaneBlock.FCStd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]
2023-03-17 Add Power Distribution PCB
    [BackplaneBlockTest.FCStd, BackplaneBlockTest.stl, BackplaneFrontPanel.FCStd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]
2023-03-17 Fix PCB template problems
    [YamhillPowerDistribution.kicad_pcb, YamhillTemplate1x1.kicad_pcb, YamhillTemplate1x1.kicad_sch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]
2023-04-07 Update architecture doc, add prelim front panel
    [YamhillFrontPanel.kicad_pcb, YamhillFrontPanel.kicad_sch]
2023-07-07 First pass of front panel circuit
    [FrontPanelAnalog.kicad_sch, FrontPanelDigital.kicad_sch, YamhillFrontPanel.kicad_sch]
2023-09-05 Rev A Front Panel
    [FrontPanelAnalog.kicad_sch, FrontPanelDigital.kicad_sch, SMA-J-P-H-ST-TH1.igs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]
2023-09-05 Update Front Panel sch PDF for Rev A
    [FrontPanelAnalog.kicad_sch, FrontPanelDigital.kicad_sch, YamhillFrontPanel.kicad_sch]
2023-09-06 Update 1x1 template
    [YamhillTemplate1x1.kicad_pcb]
2023-09-06 Add Diode Ring Mixer Board
    [YamhillDiodeRingMixer.kicad_pcb, YamhillDiodeRingMixer.kicad_sch, YamhillTemplate1x1.kicad_pcb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]
2023-09-12 Tweak footprint on diode mixer
    [YamhillDiodeRingMixer.kicad_pcb, YamhillDiodeRingMixer.kicad_sch]
2023-10-14 Add AF Feedback Amp PCB
    [YamhillAFFeedbackAmp.kicad_pcb, YamhillAFFeedbackAmp.kicad_sch, YamhillDualDoubleTunedCircuit.kicad_pcb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]
2023-11-04 Update arch document
    [YamhillJFETPreamp.kicad_pcb, YamhillJFETPreamp.kicad_sch]
2023-12-20 Add Active AF Filter board
    [YamhillAFFeedbackAmp.kicad_sch, YamhillActiveAFFilter.kicad_pcb, YamhillActiveAFFilter.kicad_sch]
2024-01-03 AF Filter, Protoboard modules added
    [FrontPanelDigital.kicad_sch, YamhillActiveAFFilter.kicad_pcb, YamhillActiveAFFilter.kicad_sch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]
2024-01-13 Update all PCBs for first tranche order
    [FrontPanelAnalog.kicad_sch, FrontPanelDigital.kicad_sch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]
2024-02-25 Arch document update
    [FrontPanelAnalog.kicad_sch, FrontPanelDigital.kicad_sch, YamhillFrontPanel.kicad_pcb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]
2024-05-24 Front Panel Rev B revisions
    [FrontPanelAnalog.kicad_sch, FrontPanelDigital.kicad_sch, YamhillActiveAFFilter.kicad_pcb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]
2024-07-10 Second tranche of PCBs
    [FrontPanelAnalog.kicad_sch, FrontPanelDigital.kicad_sch, YamhillActiveAFFilter.kicad_pcb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]

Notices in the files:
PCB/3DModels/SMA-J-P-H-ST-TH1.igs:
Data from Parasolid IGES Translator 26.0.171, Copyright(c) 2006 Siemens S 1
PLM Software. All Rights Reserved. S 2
